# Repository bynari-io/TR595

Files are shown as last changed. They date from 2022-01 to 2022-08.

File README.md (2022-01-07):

# TR-595 Tricorder Project

This project is my attempt to build a customized version of the Voyager Mk IX/X Tricorder. The project will consist of a 3D printed housing and will utilize an LCD display and custom electronics driven by a Raspberry Pi Pico. All designs and code will be freely available in this repository. For more information, see the developmnent thread on the RPF: https://www.therpf.com/forums/threads/tr-595e-custom-tricorder.342650/

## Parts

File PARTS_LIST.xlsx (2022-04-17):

TR-595 Part List
2022 Arky's Lab
FRONT ARRAY
LABEL | TYPE | VALUE | PACKAGE | Notes
C1 | CAPACITOR | 4.7uF | 0805 SMD
C2 | CAPACITOR | 0.01uF | 0805 SMD
C3 | CAPACITOR | 2.2uF | 0805 SMD
C4 | CAPACITOR | 0.01uF | 0805 SMD
D1 | LED | AMBER | 0805 SMD | P/N 150080AS75000
D2 | LED | AMBER | 0805 SMD | P/N 150080AS75000
D3 | LED | AMBER | 0805 SMD | P/N 150080AS75000
D4 | LED | AMBER | 0805 SMD | P/N 150080AS75000
D5 | LED | AMBER | 0805 SMD | P/N 150080AS75000
D6 | LED | AMBER | 0805 SMD | P/N 150080AS75000
D7 | LED | AMBER | 0805 SMD | P/N 150080AS75000
D8 | LED | AMBER | 0805 SMD | P/N 150080AS75000
D9 | LED | GREEN | 0805 SMD | P/N 150080VS75000
D10 | LED | GREEN | 0805 SMD | P/N 150080VS75000
D11 | LED | GREEN | 0805 SMD | P/N 150080VS75000
D12 | LED | GREEN | 0805 SMD | P/N 150080VS75000
D13 | LED | GREEN | 0805 SMD | P/N 150080VS75000
D14 | LED | GREEN | 0805 SMD | P/N 150080VS75000
D15 | LED | GREEN | 0805 SMD | P/N 150080VS75000
D16 | LED | GREEN | 0805 SMD | P/N 150080VS75000
D17 | LED | GREEN | 0805 SMD | P/N 150080VS75000
D18 | LED | GREEN | 0805 SMD | P/N 150080VS75000
D19 | LED | GREEN | 0805 SMD | P/N 150080VS75000
D20 | LED | GREEN | 0805 SMD | P/N 150080VS75000
D21 | LED | GREEN | 0805 SMD | P/N 150080VS75000
D22 | LED | GREEN | 0805 SMD | P/N 150080VS75000
D23 | LED | AMBER | 0805 SMD | P/N 150080AS75000
D24 | LED | AMBER | 0805 SMD | P/N 150080AS75000
D25 | LED | AMBER | 0805 SMD | P/N 150080AS75000
D26 | LED | RED | 0805 SMD | P/N 150080SS75000
D27 | LED | RED | 0805 SMD | P/N 150080SS75000
D28 | LED | RED | 0805 SMD | P/N 150080SS75000
IC1 | IC | NE555_SOIC | SO16
IC2 | IC | NE555_SOIC | SO16
IC3 | IC | 4017D | SO16 | P/N 74HC4017D,653
IC4 | IC | 4017D | SO16 | P/N 74HC4017D,653
R1 | RESISTOR | 100K | 0805 SMD
R2 | RESISTOR | 200 | 0805 SMD
R3 | RESISTOR | 82 | 0805 SMD
R4 | RESISTOR | 100K | 0805 SMD
R5 | RESISTOR | 200 | 0805 SMD
R6 | RESISTOR | 82 | 0805 SMD
R7 | RESISTOR | 150 | 0805 SMD
R8 | RESISTOR | 150 | 0805 SMD
R9 | RESISTOR | 150 | 0805 SMD
R10 | RESISTOR | 150 | 0805 SMD
R11 | RESISTOR | 150 | 0805 SMD
R12 | RESISTOR | 150 | 0805 SMD
R13 | RESISTOR | 150 | 0805 SMD
R14 | RESISTOR | 150 | 0805 SMD
R15 | RESISTOR | 150 | 0805 SMD
R16 | RESISTOR | 150 | 0805 SMD
R17 | RESISTOR | 150 | 0805 SMD
R18 | RESISTOR | 150 | 0805 SMD
LOWER INTERFACE
LABEL | TYPE | VALUE | PACKAGE | Notes
C1 | CAPACITOR | 3.3uF | 0805 SMD
C2 | CAPACITOR | 0.01uF | 0805 SMD
D1 | LED | GREEN | 0805 SMD | P/N 150080VS75000
D2 | LED | GREEN | 0805 SMD | P/N 150080VS75000
D3 | LED | GREEN | 0805 SMD | P/N 150080VS75000
D4 | LED | GREEN | 0805 SMD | P/N 150080VS75000
D5 | LED | AMBER | 0805 SMD | P/N 150080AS75000
D6 | LED | AMBER | 0805 SMD | P/N 150080AS75000
D7 | LED | AMBER | 0805 SMD | P/N 150080AS75000
D8 | LED | AMBER | 0805 SMD | P/N 150080AS75000
D9 | LED | RED | 0805 SMD | P/N 150080SS75000
IC1 | IC | NE555_SOIC | SO16
IC2 | IC | 4017D | SO16 | P/N 74HC4017D,653
R1 | RESISTOR | 100K | 0805 SMD
R2 | RESISTOR | 200 | 0805 SMD
R3 | RESISTOR | 150 | 0805 SMD
R4 | RESISTOR | 150 | 0805 SMD
R5 | RESISTOR | 150 | 0805 SMD
R6 | RESISTOR | 150 | 0805 SMD
R7 | RESISTOR | 150 | 0805 SMD
R8 | RESISTOR | 150 | 0805 SMD
LOWER INTERFACE
LABEL | TYPE | VALUE | PACKAGE | Notes
D1 | LED | RED | 0805 SMD | P/N 150080SS75000
D2 | LED | GREEN | 0805 SMD | P/N 150080VS75000
D3 | LED | GREEN | 0805 SMD | P/N 150080VS75000
D4 | LED | RED | 0805 SMD | P/N 150080SS75000
D5 | LED | RED | 0805 SMD | P/N 150080SS75000
D6 | LED | AMBER | 0805 SMD | P/N 150080AS75000
D7 | LED | AMBER | 0805 SMD | P/N 150080AS75000
R1 | RESISTOR | 150 | 0805 SMD
R2 | RESISTOR | 150 | 0805 SMD
R3 | RESISTOR | 150 | 0805 SMD
R4 | RESISTOR | 150 | 0805 SMD
R5 | RESISTOR | 150 | 0805 SMD
R6 | RESISTOR | 150 | 0805 SMD
R7 | RESISTOR | 150 | 0805 SMD
OTHER
REED SWITCH |  | LITTELFUSE MAGNETIC/REED SWITCH P/N MDRR-DT-15-F
LCD SCREEN |  | https://www.adafruit.com/product/1480
BATTERY |  | https://www.adafruit.com/product/258
CHARGER |  | https://www.adafruit.com/product/1905
QI RECEIVER |  | https://www.digikey.com/en/products/detail/adafruit-industries-llc/1901/5629432
PAINT |  | DUPLICOLOR BGM0347 MEDIUM GRAY METALLIC
HINGES |  | STANLEY CLASSIC BRASSWARE 80-3050 3/4" (19mm)
MICROCONTROLLER |  | RASPBERRY PI PICO

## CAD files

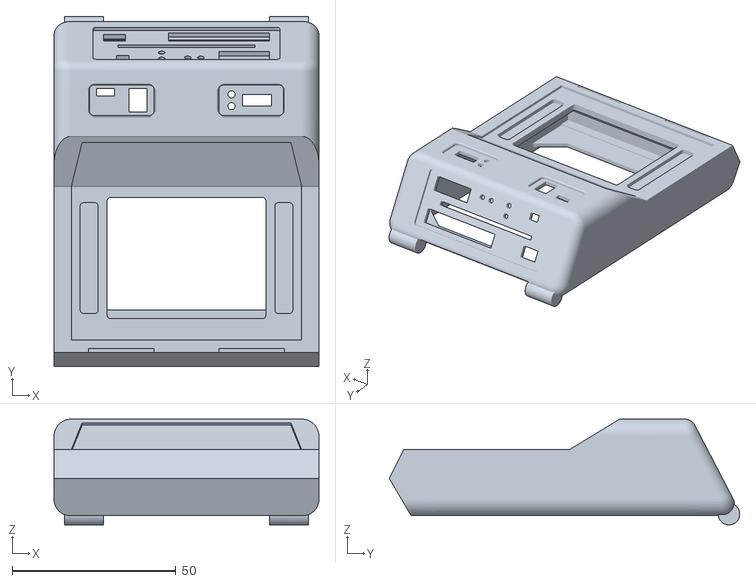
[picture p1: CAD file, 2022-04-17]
STL/Main Body.stl
81.0 x 107.1 x 32.3

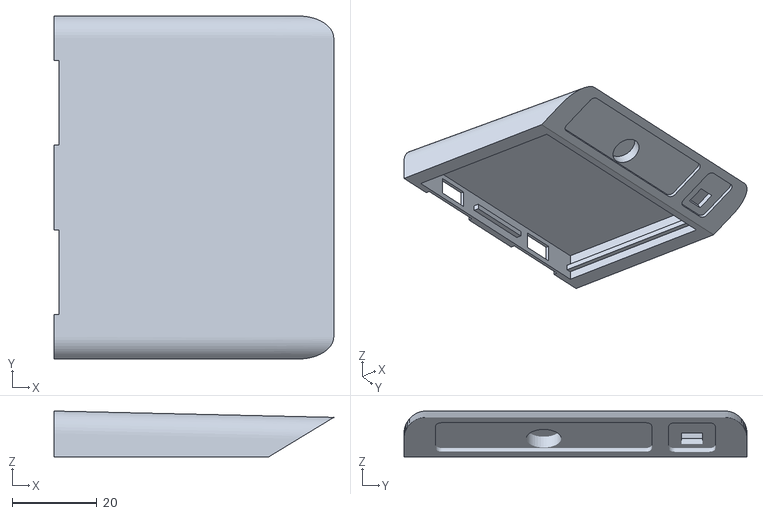
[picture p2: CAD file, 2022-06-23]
STL/Door 5.1 (ID Cutout).stl
66.0 x 81.0 x 10.9

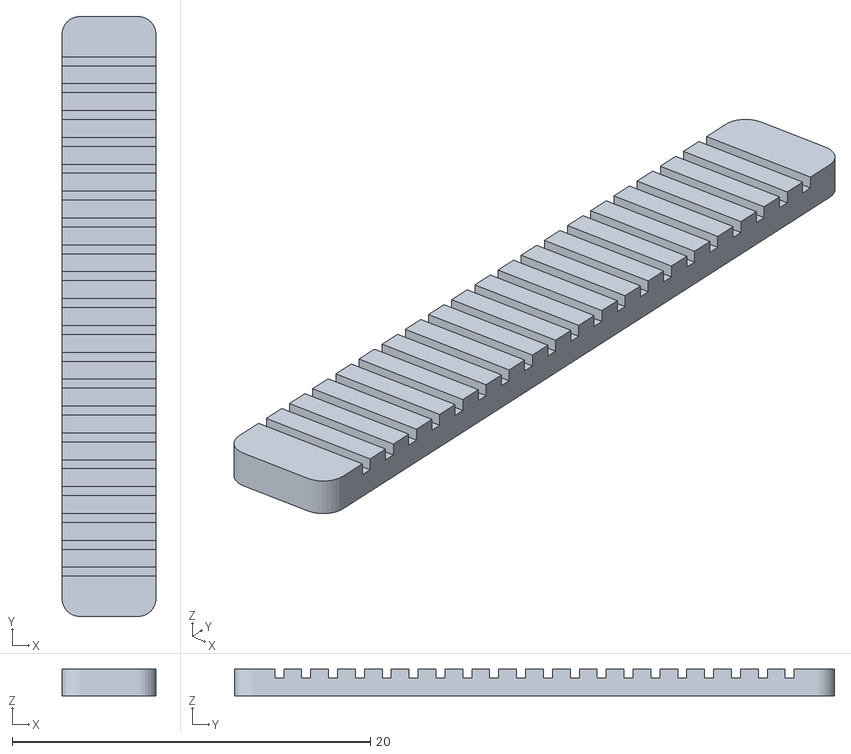
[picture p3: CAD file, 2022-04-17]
STL/Panel Greeblies.stl
5.25 x 33.5 x 1.50

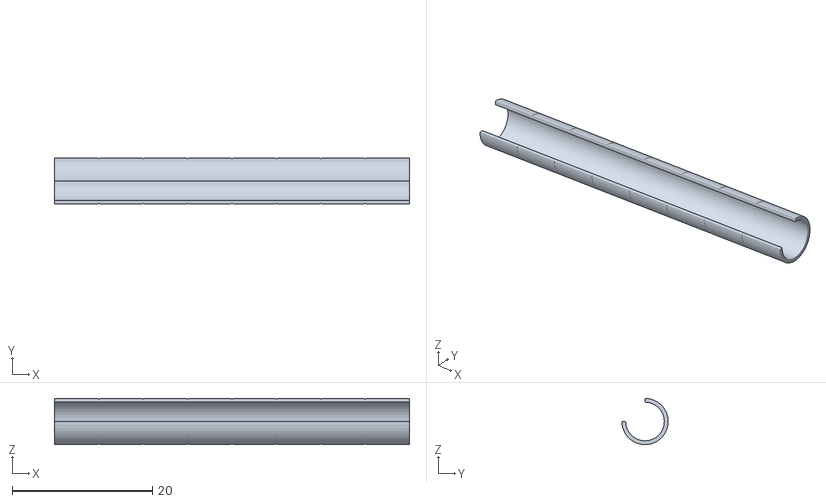
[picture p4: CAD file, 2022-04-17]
STL/Front Array Greeblie.stl
50.6 x 6.60 x 6.60

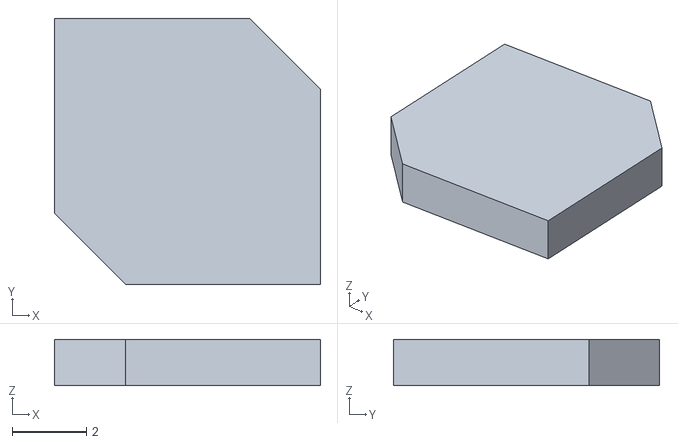
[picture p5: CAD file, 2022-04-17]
STL/EMRG.stl
7.16 x 7.15 x 1.25

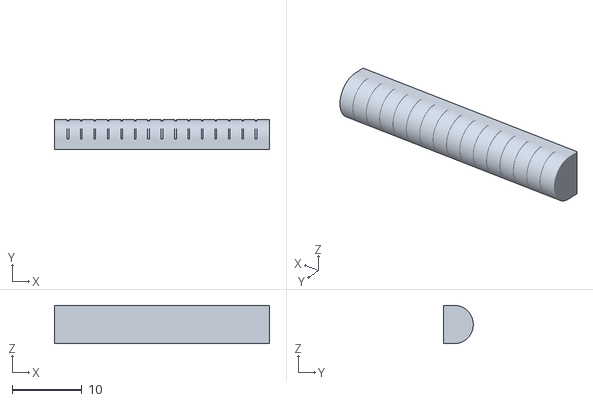
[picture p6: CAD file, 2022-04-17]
STL/Front Greeblie LG.stl
30.8 x 4.25 x 5.50

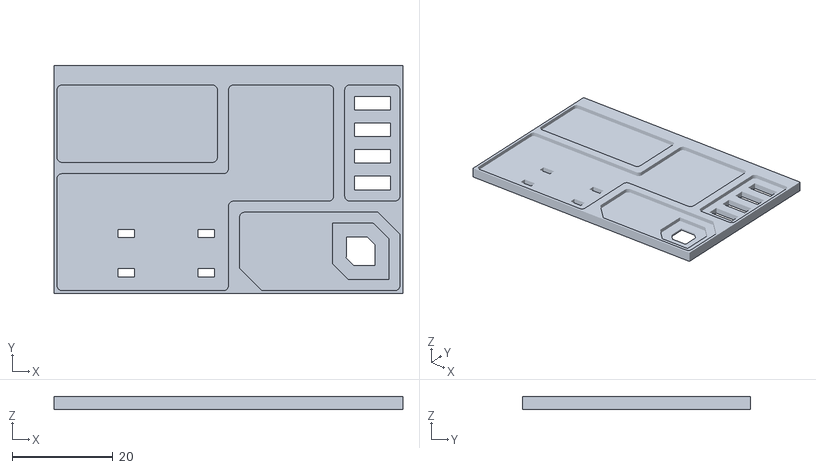
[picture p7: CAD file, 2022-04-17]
STL/Lower Interface.stl
69.4 x 45.4 x 2.50

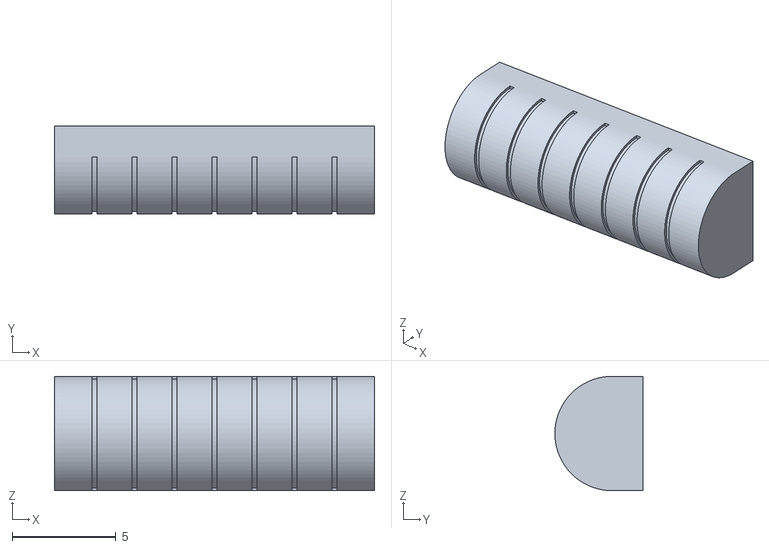
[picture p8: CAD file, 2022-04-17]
STL/Front Greeblie SM.stl
15.4 x 4.25 x 5.50

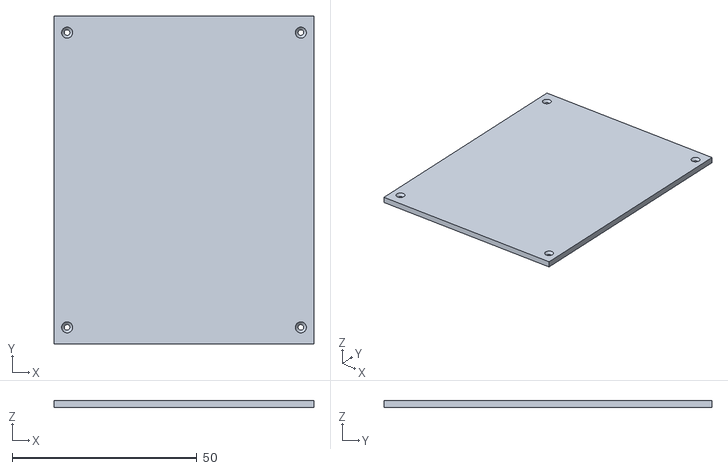
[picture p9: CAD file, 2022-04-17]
STL/Back Panel.stl
70.2 x 88.8 x 2.00

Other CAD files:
STL/Door.stl
F360 Exports/Back Panel.f3d
F360 Exports/Door 5.1 (ID Cutout).f3z
F360 Exports/Door.f3z
F360 Exports/EMRG.f3d
F360 Exports/Electronics/Lower Interface Electronics.f3z
F360 Exports/Electronics/Top Panel Electronics.f3z
F360 Exports/Front Array Greeblie.f3d
F360 Exports/Front Greeblie LG.f3d
F360 Exports/Front Greeblie SM.f3d
F360 Exports/Lower Interface.f3d
F360 Exports/Main Body.f3z
F360 Exports/Panel Greeblie.f3d

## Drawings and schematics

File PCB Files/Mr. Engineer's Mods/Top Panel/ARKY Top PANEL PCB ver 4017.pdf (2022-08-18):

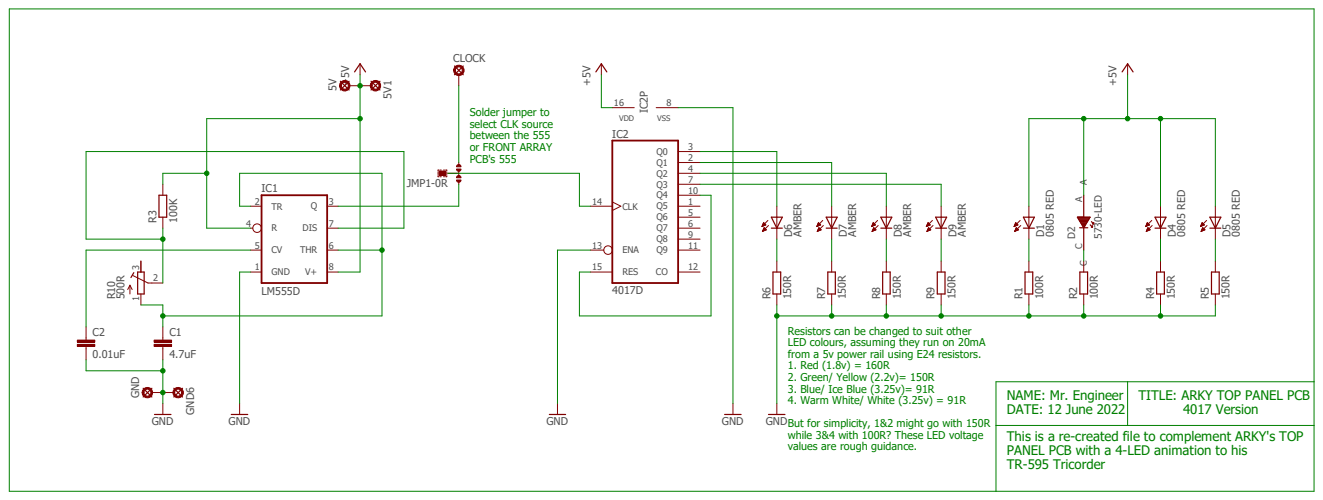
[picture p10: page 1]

Resistors can be changed to suit other
LED colours, assuming they run on 20mA
from a 5v power rail using E24 resistors.
1. Red (1.8v) = 160R
2. Green/ Yellow (2.2v)= 150R
3. Blue/ Ice Blue (3.25v)= 91R
4. Warm White/ White (3.25v) = 91R
But for simplicity, 1&2 might go with 150R
while 3&4 with 100R? These LED voltage
values are rough guidance.

NAME: Mr. Engineer
DATE: 12 June 2022
This is a re-created file to complement ARKY's TOP
PANEL PCB with a 4-LED animation to his
TR-595 Tricorder

TITLE: ARKY TOP PANEL PCB
4017 Version

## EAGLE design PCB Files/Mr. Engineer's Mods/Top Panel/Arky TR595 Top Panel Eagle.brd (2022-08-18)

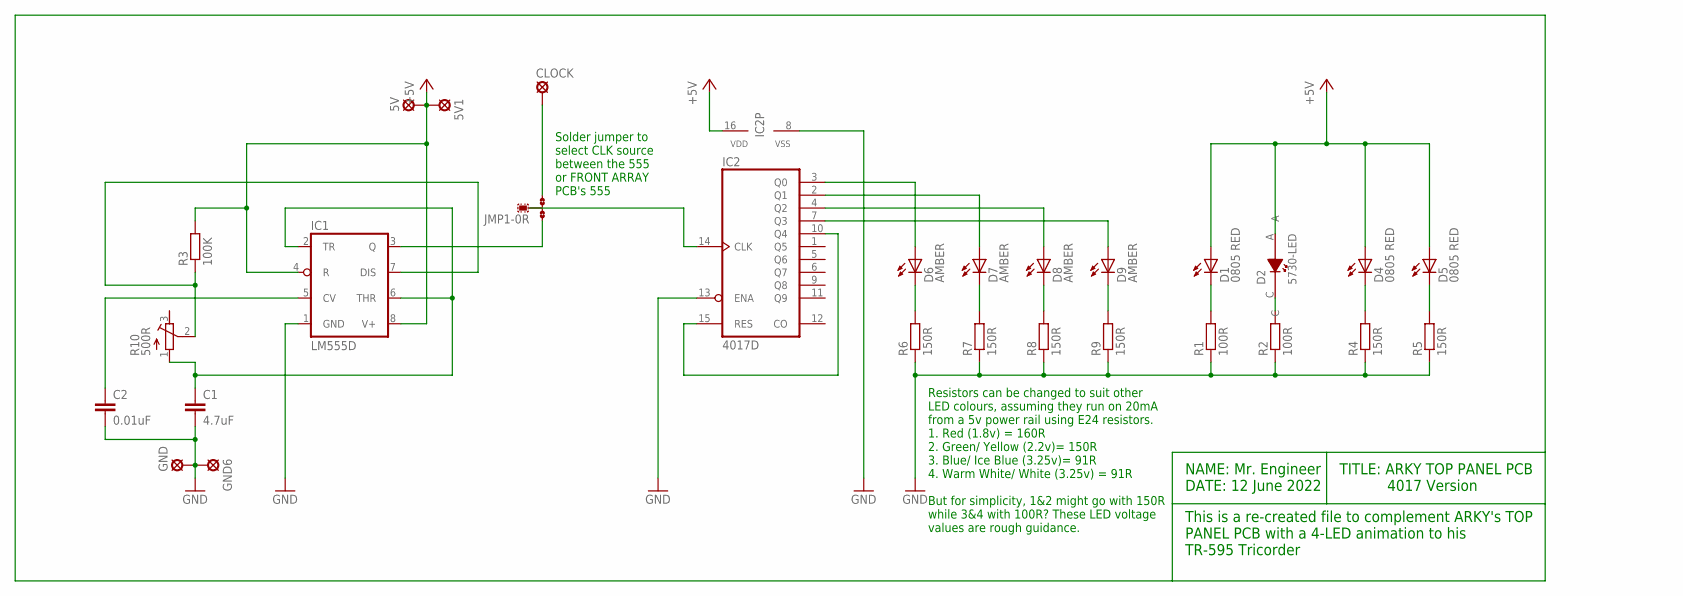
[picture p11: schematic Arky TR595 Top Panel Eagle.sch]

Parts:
5V, 5V1: MCS10B
C1: 4.7uF; C0805
C2: 0.01uF; C0805
CLOCK: MCS10B
D1, D4, D5: 0805 RED; CHIPLED_0805
D2: 5730-LED
D6, D7, D8, D9: AMBER; CHIPLED_0805
GND, GND6: MCS10B
IC1: LM555D; SO08
IC2: 4017D; SO16
JMP1: 0R-JUMPA; A0R-JMP
R1, R2: 100R; R0805
R3: 100K; R0805
R4, R5, R6, R7, R8, R9: 150R; R0805
R10: 500R; RTRIM3103

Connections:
+5V: 5V.MP, 5V1.MP, D1.A, D2.A, D4.A, D5.A, IC1.4 (R), IC1.8 (V+), IC2.16 (VDD), R3.2
GND: IC2.8 (VSS)
unnamed: IC1.3 (Q), JMP1.1
unnamed: C2.1, IC1.5 (CV)
unnamed: D6.C, R6.2
unnamed: D7.C, R7.2
unnamed: D8.C, R8.2
unnamed: D9.C, R9.2
unnamed: C1.1, IC1.2 (TR), IC1.6 (THR), R10.1 (A)
unnamed: D6.A, IC2.3 (Q0)
unnamed: D7.A, IC2.2 (Q1)
unnamed: D8.A, IC2.4 (Q2)
unnamed: D9.A, IC2.7 (Q3)
unnamed: IC2.10 (Q4), IC2.15 (RES)
unnamed: D4.C, R4.2
unnamed: D5.C, R5.2
unnamed: D1.C, R1.2
unnamed: D2.C, R2.2
unnamed: IC1.7 (DIS), R3.1, R10.2 (S)
unnamed: IC2.14 (CLK), JMP1.2
unnamed: CLOCK.MP, JMP1.3
unnamed: C1.2, C2.2, GND.MP, GND6.MP, IC1.1 (GND), IC2.13 (ENA), R1.1, R2.1, R4.1, R5.1, R6.1, R7.1, R8.1, R9.1

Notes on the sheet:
This is a re-created file to complement ARKY's TOP PANEL PCB with a 4-LED animation to his TR-595 Tricorder
NAME: Mr. Engineer DATE: 12 June 2022
TITLE: ARKY TOP PANEL PCB 4017 Version
Solder jumper to select CLK source between the 555 or FRONT ARRAY PCB's 555
Resistors can be changed to suit other LED colours, assuming they run on 20mA from a 5v power rail using E24 resistors. 1. Red (1.8v) = 160R 2. Green/ Yellow (2.2v)= 150R 3. Blue/ Ice Blue (3.25v)= 91R 4. Warm White/ White (3.25v) = 91R But for simplicity, 1&2 might go with 150R while 3&4 with 100R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

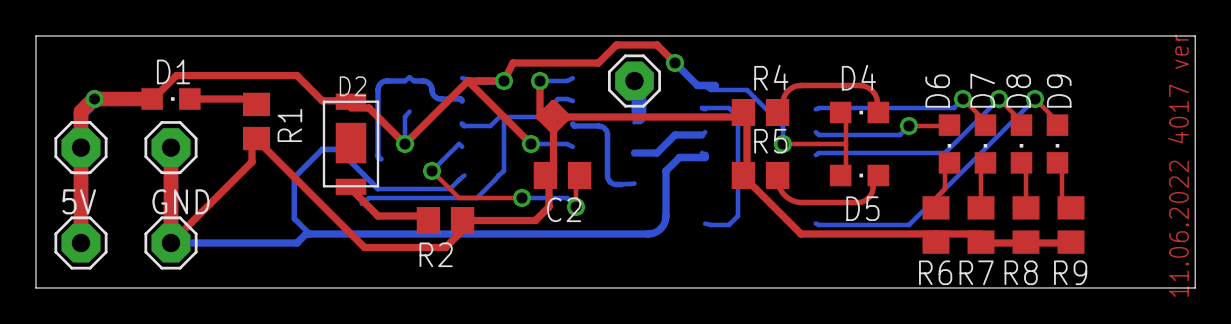
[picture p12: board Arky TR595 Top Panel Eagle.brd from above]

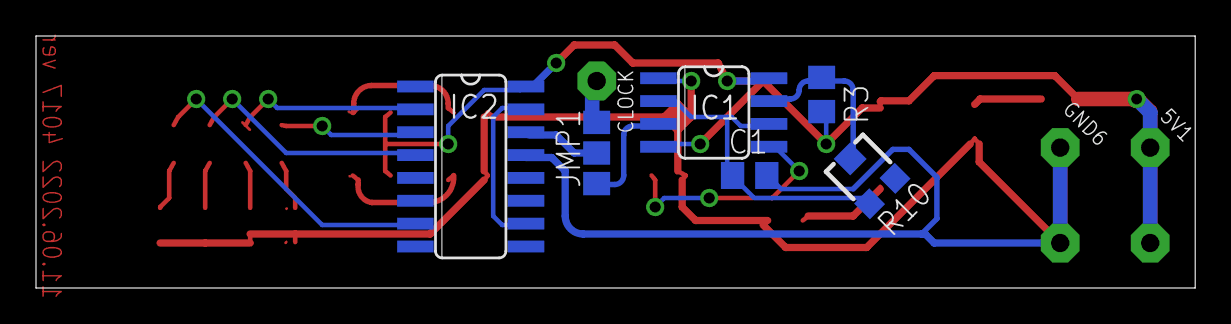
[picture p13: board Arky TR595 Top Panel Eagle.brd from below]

Board: 2 copper layers, 64.4 x 14.0 mm, 28 parts (6 on the bottom side), 21 nets.

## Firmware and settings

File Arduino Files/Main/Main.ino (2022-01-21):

// Libraries
#include <TFT_eSPI.h>
#include "tr595.h"

// Assets
#include "defaultmode.h"
#include "dm_button_red.h"
#include "dm_button_orange.h"
#include "dm_line1_orange.h"
#include "dm_line2_orange.h"
#include "dm_line3_orange.h"
#include "dm_line4_orange.h"
#include "dm_line5_orange.h"
#include "dm_line6_orange.h"
#include "dm_line1_white.h"
#include "dm_line2_white.h"
#include "dm_line3_white.h"
#include "dm_line4_white.h"
#include "dm_line5_white.h"
#include "dm_line6_white.h"


//TFT_eSPI instance
TFT_eSPI tft = TFT_eSPI();

// Constants
const int DISPLAY_WIDTH = 320;
const int DISPLAY_HEIGHT = 240;

// Sprites

// **Default Mode** //
TFT_eSprite dm_spr_frameTop = TFT_eSprite(&tft);
TFT_eSprite dm_bg_frameTop = TFT_eSprite(&tft);
TFT_eSprite dm_spr_frameBottom = TFT_eSprite(&tft);
TFT_eSprite dm_bg_frameBottom = TFT_eSprite(&tft);
TFT_eSprite dm_bg_button = TFT_eSprite(&tft);
TFT_eSprite dm_spr_barGraph = TFT_eSprite(&tft);
TFT_eSprite dm_bg_barGraph = TFT_eSprite(&tft);
TFT_eSprite dm_bg_scrollText = TFT_eSprite(&tft);

// Animation Elements

// **Default Mode** //
Anim dm_frameTop;
Anim dm_frameBottom;
Anim dm_button1;
Anim dm_button2;
Anim dm_button3;
Anim dm_bargraph1;
Anim dm_bargraph2;
Anim dm_bargraph3;
Anim dm_bargraph4;
Anim dm_bargraph5;
Anim dm_bargraph6;
Anim dm_bargraph7;
Anim dm_bargraph8;
Anim dm_line1;
Anim dm_line2;
Anim dm_line3;
Anim dm_line4;
Anim dm_line5;
Anim dm_line6;


// Variables
unsigned long currentMillis = 0;

// Functions

void setup() {

  pinMode(LED_BUILTIN, OUTPUT); // Used for diagnostic purposes
  
  // Initialize TFT & clear the screen
  TFTSetup();
  tft.fillScreen(TFT_BLACK);

  //Initialize all modes
  DM_InitializeAttributes();
  randomSeed(millis());

  // Begin Default Mode animation sequence
  DM_Loop(); 
}

void loop() {  
}

void TFTSetup(){

  Serial.begin(115200);
  tft.begin();
  tft.setRotation(1); // Set display to landscape

  //Swap the color byte order when rendering
  tft.setSwapBytes(true);
    
}

void DrawBackgroundImage(int x, int y, int w, int h, const unsigned short IMAGE[]) {

  // Clear screen & draw background image
  //tft.fillScreen(TFT_BLACK);
  tft.pushImage(x, y, w, h, IMAGE);
      
}

void ShowLED() {
  digitalWrite(LED_BUILTIN, HIGH);   // turn the LED on (HIGH is the voltage level)                   
}

/////////////////////
// ANIMATION LOGIC //
/////////////////////

// ***** DEFAULT MODE *** ////////////////////////////////////////////////////////////////

void DM_InitializeAttributes(){

// Text Line 1
dm_line1.sizeX = 171;    // Size attributes will be used for the entire sequence
dm_line1.sizeY = 4;
dm_line1.currentX = 70;
dm_line1.currentY = 8;
dm_line1.interval = 500; // This interval will be used for the entire sequence
dm_line1.sCounter = 0;   // This counter will be used for the entire sequence
dm_line1.previousMillis = 0;   // This will be used for the entire sequence


// Text Line 2
dm_line2.currentX = 70;
dm_line2.currentY = 13;

// Text Line 3
dm_line3.currentX = 70;
dm_line3.currentY = 18;

//Text Line 4
dm_line4.currentX = 70;
dm_line4.currentY = 23;

// Text Line 5
dm_line5.currentX = 70;
dm_line5.currentY = 28;

//Text Line 6
dm_line6.currentX = 70;
dm_line6.currentY = 33;

// Bargraph 1
dm_bargraph1.sizeX = 23;
dm_bargraph1.sizeY = 5;
dm_bargraph1.maxX = 23;
dm_bargraph1.maxY = 95;
dm_bargraph1.currentX = 92;
dm_bargraph1.currentY = dm_bargraph1.bargraphBottom - dm_bargraph1.sizeY;
dm_bargraph1.bargraphBottom = 188;
dm_bargraph1.interval = 20;
dm_bargraph1.bargraphSpeed = 1;

// Bargraph 2
dm_bargraph2.sizeX = 23;
dm_bargraph2.sizeY = 5;
dm_bargraph2.maxX = 23;
dm_bargraph2.maxY = 95;
dm_bargraph2.currentX = 117;
dm_bargraph2.currentY = dm_bargraph2.bargraphBottom - dm_bargraph2.sizeY;
dm_bargraph2.bargraphBottom = 188;
dm_bargraph2.interval = 20;
dm_bargraph2.bargraphSpeed = 1;

// Bargraph 3
dm_bargraph3.sizeX = 23;
dm_bargraph3.sizeY = 5;
dm_bargraph3.maxX = 23;
dm_bargraph3.maxY = 95;
dm_bargraph3.currentX = 142;
dm_bargraph3.currentY = dm_bargraph1.bargraphBottom - dm_bargraph1.sizeY;
dm_bargraph3.bargraphBottom = 188;
dm_bargraph3.interval = 20;
dm_bargraph3.bargraphSpeed = 1;

// Bargraph 4
dm_bargraph4.sizeX = 23;
dm_bargraph4.sizeY = 5;
dm_bargraph4.maxX = 23;
dm_bargraph4.maxY = 95;
dm_bargraph4.currentX = 167;
dm_bargraph4.currentY = dm_bargraph4.bargraphBottom - dm_bargraph4.sizeY;
dm_bargraph4.bargraphBottom = 188;
dm_bargraph4.interval = 20;
dm_bargraph4.bargraphSpeed = 1;

// Bargraph 5
dm_bargraph5.sizeX = 23;
dm_bargraph5.sizeY = 5;
dm_bargraph5.maxX = 23;
dm_bargraph5.maxY = 95;
dm_bargraph5.currentX = 192;
dm_bargraph5.currentY = dm_bargraph5.bargraphBottom - dm_bargraph5.sizeY;
dm_bargraph5.bargraphBottom = 188;
dm_bargraph5.interval = 20;
dm_bargraph5.bargraphSpeed = 1;

// Bargraph 6
dm_bargraph6.sizeX = 23;
dm_bargraph6.sizeY = 5;
dm_bargraph6.maxX = 23;
dm_bargraph6.maxY = 95;
dm_bargraph6.currentX = 217;
dm_bargraph6.currentY = dm_bargraph6.bargraphBottom - dm_bargraph6.sizeY;
dm_bargraph6.bargraphBottom = 188;
dm_bargraph6.interval = 20;
dm_bargraph6.bargraphSpeed = 1;

// Bargraph 7
dm_bargraph7.sizeX = 23;
dm_bargraph7.sizeY = 5;
dm_bargraph7.maxX = 23;
dm_bargraph7.maxY = 95;
dm_bargraph7.currentX = 242;
dm_bargraph7.currentY = dm_bargraph7.bargraphBottom - dm_bargraph7.sizeY;
dm_bargraph7.bargraphBottom = 188;
dm_bargraph7.interval = 20;
dm_bargraph7.bargraphSpeed = 1;

// Bargraph 8
dm_bargraph8.sizeX = 23;
dm_bargraph8.sizeY = 5;
dm_bargraph8.maxX = 23;
dm_bargraph8.maxY = 95;
dm_bargraph8.currentX = 267;
dm_bargraph8.currentY = dm_bargraph8.bargraphBottom - dm_bargraph8.sizeY;
dm_bargraph8.bargraphBottom = 188;
dm_bargraph8.interval = 20;
dm_bargraph8.bargraphSpeed = 1;

// Button 1
dm_button1.sizeX = 32;
dm_button1.sizeY = 12;
dm_button1.currentX = 211;
dm_button1.currentY = 214;
dm_button1.interval = 2000;

// Button 2
dm_button2.sizeX = 32;
dm_button2.sizeY = 12;
dm_button2.currentX = 245;
dm_button2.currentY = 214;
dm_button2.interval = 500;

// Button 3
dm_button3.sizeX = 32;
dm_button3.sizeY = 12;
dm_button3.currentX = 279;
dm_button3.currentY = 214;
dm_button3.interval = 750;

// Frame Top
dm_frameTop.sizeX = 8;
dm_frameTop.sizeY = 5;
dm_frameTop.minX = 136;
dm_frameTop.minY = 59;
dm_frameTop.maxX = 173;
dm_frameTop.maxY = 59;
dm_frameTop.currentX = dm_frameTop.maxX;
dm_frameTop.currentY = dm_frameTop.minY;
dm_frameTop.oldX = dm_frameTop.currentX;
dm_frameTop.oldY = dm_frameTop.currentY;
dm_frameTop.reverse = true;
dm_frameTop.interval = 20;

// Frame Bottom
dm_frameBottom.sizeX = 8;
dm_frameBottom.sizeY = 5;
dm_frameBottom.minX = 136;
dm_frameBottom.minY = 230;
dm_frameBottom.maxX = 173;
dm_frameBottom.maxY = 230;
dm_frameBottom.currentX = dm_frameBottom.minX;
dm_frameBottom.currentY = dm_frameBottom.minY;
dm_frameBottom.oldX = dm_frameBottom.currentX;
dm_frameBottom.oldY = dm_frameBottom.currentY;
dm_frameBottom.reverse = false;
dm_frameBottom.interval = 20;

}

// Begin Default Mode Loop
void DM_Loop(){

  DrawBackgroundImage(0, 0, DISPLAY_WIDTH, DISPLAY_HEIGHT, defaultmode);

  while(true){

    currentMillis = millis();
    DM_FrameTop();
    DM_FrameBottom();
    DM_Button1();
    DM_Button2();
    DM_Button3();
    DM_Bargraph1();
    DM_Bargraph2();
    DM_Bargraph3();
    DM_Bargraph4();
    DM_Bargraph5();
    DM_Bargraph6();
    DM_Bargraph7();
    DM_Bargraph8();
    DM_ScrollingText();
    
  }
   
}

void DM_ScrollingText(){

  if (CheckTime(currentMillis, dm_line1.previousMillis, dm_line1.interval)) {

    if (dm_line1.sCounter == 0){
      // Draw first line
      DrawBackgroundImage(dm_line1.currentX, dm_line1.currentY, dm_line1.sizeX, dm_line1.sizeY, dm_line1_orange);

    }

    if (dm_line1.sCounter == 1){
      // Draw second line
      DrawBackgroundImage(dm_line2.currentX, dm_line2.currentY, dm_line1.sizeX, dm_line1.sizeY, dm_line2_orange);

    }

    if (dm_line1.sCounter == 2){
      // Draw third line
      DrawBackgroundImage(dm_line3.currentX, dm_line3.currentY, dm_line1.sizeX, dm_line1.sizeY, dm_line3_orange);

    }

    if (dm_line1.sCounter == 3){
      // Draw fourth line
      DrawBackgroundImage(dm_line4.currentX, dm_line4.currentY, dm_line1.sizeX, dm_line1.sizeY, dm_line4_orange);

    }
    
    if (dm_line1.sCounter == 4){
      // Draw fifth line
      DrawBackgroundImage(dm_line5.currentX, dm_line5.currentY, dm_line1.sizeX, dm_line1.sizeY, dm_line5_orange);

    }
    
    if (dm_line1.sCounter == 5){
      // Draw sixth line
      DrawBackgroundImage(dm_line6.currentX, dm_line6.currentY, dm_line1.sizeX, dm_line1.sizeY, dm_line6_orange);

    }

    if (dm_line1.sCounter == 6){
      // highlight first and second lines
      DrawBackgroundImage(dm_line1.currentX, dm_line1.currentY, dm_line1.sizeX, dm_line1.sizeY, dm_line1_white);
      DrawBackgroundImage(dm_line2.currentX, dm_line2.currentY, dm_line1.sizeX, dm_line1.sizeY, dm_line2_white);

    }

    if (dm_line1.sCounter == 7){
      // restore first and second lines, highlight third and fourth lines
      DrawBackgroundImage(dm_line1.currentX, dm_line1.currentY, dm_line1.sizeX, dm_line1.sizeY, dm_line1_orange);
      DrawBackgroundImage(dm_line2.currentX, dm_line2.currentY, dm_line1.sizeX, dm_line1.sizeY, dm_line2_orange);
      
      DrawBackgroundImage(dm_line3.currentX, dm_line3.currentY, dm_line1.sizeX, dm_line1.sizeY, dm_line3_white);
      DrawBackgroundImage(dm_line4.currentX, dm_line4.currentY, dm_line1.sizeX, dm_line1.sizeY, dm_line4_white);

    }

    if (dm_line1.sCounter == 8){
      // restore third and fourth lines, highlight fifth and sixth lines
      DrawBackgroundImage(dm_line3.currentX, dm_line3.currentY, dm_line1.sizeX, dm_line1.sizeY, dm_line3_orange);
      DrawBackgroundImage(dm_line4.currentX, dm_line4.currentY, dm_line1.sizeX, dm_line1.sizeY, dm_line4_orange);
      
      DrawBackgroundImage(dm_line5.currentX, dm_line5.currentY, dm_line1.sizeX, dm_line1.sizeY, dm_line5_white);
      DrawBackgroundImage(dm_line6.currentX, dm_line6.currentY, dm_line1.sizeX, dm_line1.sizeY, dm_line6_white);

    }

    if (dm_line1.sCounter == 9){
      // restore fifth and sixth lines
      DrawBackgroundImage(dm_line5.currentX, dm_line5.currentY, dm_line1.sizeX, dm_line1.sizeY, dm_line5_orange);
      DrawBackgroundImage(dm_line6.currentX, dm_line6.currentY, dm_line1.sizeX, dm_line1.sizeY, dm_line6_orange);

    }

    if (dm_line1.sCounter == 10){
      // Erase all text
      dm_bg_scrollText.createSprite(174, 31);
      dm_bg_scrollText.fillSprite(TFT_BLACK);
      dm_bg_scrollText.pushSprite(68, 7);
      dm_bg_scrollText.deleteSprite();

      // Reset counter to end sequence
      dm_line1.sCounter = 0;
      dm_line1.previousMillis = currentMillis;
      return;
    }
    
    dm_line1.sCounter++;
    dm_line1.previousMillis = currentMillis;
  }
  
}

void DM_Bargraph1(){

  if (CheckTime(currentMillis, dm_bargraph1.previousMillis, dm_bargraph1.interval)){
    if (dm_bargraph1.sCounter == 0) {
      // Generate the next value for the bargraph, then flag the sequence counter
      dm_bargraph1.newY = random(dm_bargraph1.minY, (dm_bargraph1.maxY));

      dm_bargraph1.sCounter = 1;   
    }

    if (dm_bargraph1.newY >= dm_bargraph1.sizeY) {
      // Increase the bargraph size
      dm_bargraph1.sizeY = dm_bargraph1.sizeY + dm_bargraph1.bargraphSpeed;
      
      // Calculate the new position of the bar
      dm_bargraph1.currentY = dm_bargraph1.bargraphBottom - dm_bargraph1.sizeY;

      // Draw the new bargraph
      dm_spr_barGraph.createSprite(dm_bargraph1.sizeX, dm_bargraph1.sizeY);
      dm_spr_barGraph.fillSprite(TFT_RED);
      dm_spr_barGraph.pushSprite(dm_bargraph1.currentX, dm_bargraph1.currentY);
      dm_spr_barGraph.deleteSprite();

      if (dm_bargraph1.sizeY >= dm_bargraph1.newY){
      // Once the bargraph meets the new value, reset the sequence counter so a new value can be generated
      dm_bargraph1.sCounter = 0;
      }       
    }
    
    if (dm_bargraph1.newY < dm_bargraph1.sizeY){      
      // Decrease the bargraph size
      dm_bargraph1.sizeY = dm_bargraph1.sizeY - dm_bargraph1.bargraphSpeed;

      // To shrink the bar, we'll need to draw a black sprite over the top part of the bar.
            
      // Draw the black sprite
      dm_bg_barGraph.createSprite(dm_bargraph1.maxX, dm_bargraph1.maxY - dm_bargraph1.sizeY);
      dm_bg_barGraph.fillSprite(TFT_BLACK);
      dm_bg_barGraph.pushSprite(dm_bargraph1.currentX, dm_bargraph1.maxY - 2);
      dm_bg_barGraph.deleteSprite();
     
      
      if (dm_bargraph1.sizeY <= dm_bargraph1.newY){
      // Once the bargraph meets the new value, reset the sequence counter so a new value can be generated
      dm_bargraph1.sCounter = 0;
        }
    }    

    dm_bargraph1.previousMillis = currentMillis;    
  }
  
}

void DM_Bargraph2(){

  if (CheckTime(currentMillis, dm_bargraph2.previousMillis, dm_bargraph2.interval)){
    if (dm_bargraph2.sCounter == 0) {
      // Generate the next value for the bargraph, then flag the sequence counter
      dm_bargraph2.newY = random(dm_bargraph2.minY, (dm_bargraph2.maxY));

      dm_bargraph2.sCounter = 1;   
    }

    if (dm_bargraph2.newY >= dm_bargraph2.sizeY) {
      // Increase the bargraph size
      dm_bargraph2.sizeY = dm_bargraph2.sizeY + dm_bargraph2.bargraphSpeed;
      
      // Calculate the new position of the bar
      dm_bargraph2.currentY = dm_bargraph2.bargraphBottom - dm_bargraph2.sizeY;

      // Draw the new bargraph
      dm_spr_barGraph.createSprite(dm_bargraph2.sizeX, dm_bargraph2.sizeY);
      dm_spr_barGraph.fillSprite(TFT_RED);
      dm_spr_barGraph.pushSprite(dm_bargraph2.currentX, dm_bargraph2.currentY);
      dm_spr_barGraph.deleteSprite();

      if (dm_bargraph2.sizeY >= dm_bargraph2.newY){
      // Once the bargraph meets the new value, reset the sequence counter so a new value can be generated
      dm_bargraph2.sCounter = 0;
      }       
    }
    
    if (dm_bargraph2.newY < dm_bargraph2.sizeY){      
      // Decrease the bargraph size
      dm_bargraph2.sizeY = dm_bargraph2.sizeY - dm_bargraph2.bargraphSpeed;

      // To shrink the bar, we'll need to draw a black sprite over the top part of the bar.
            
      // Draw the black sprite
      dm_bg_barGraph.createSprite(dm_bargraph2.maxX, dm_bargraph2.maxY - dm_bargraph2.sizeY);
      dm_bg_barGraph.fillSprite(TFT_BLACK);
      dm_bg_barGraph.pushSprite(dm_bargraph2.currentX, dm_bargraph2.maxY - 2);
      dm_bg_barGraph.deleteSprite();
     
      
      if (dm_bargraph2.sizeY <= dm_bargraph2.newY){
      // Once the bargraph meets the new value, reset the sequence counter so a new value can be generated
      dm_bargraph2.sCounter = 0;
        }
    }    

    dm_bargraph2.previousMillis = currentMillis;    
  }
  
}

void DM_Bargraph3(){

  if (CheckTime(currentMillis, dm_bargraph3.previousMillis, dm_bargraph3.interval)){
    if (dm_bargraph3.sCounter == 0) {
      // Generate the next value for the bargraph, then flag the sequence counter
      dm_bargraph3.newY = random(dm_bargraph3.minY, (dm_bargraph3.maxY));

      dm_bargraph3.sCounter = 1;   
    }

    if (dm_bargraph3.newY >= dm_bargraph3.sizeY) {
      // Increase the bargraph size
      dm_bargraph3.sizeY = dm_bargraph3.sizeY + dm_bargraph3.bargraphSpeed;
      
      // Calculate the new position of the bar
      dm_bargraph3.currentY = dm_bargraph3.bargraphBottom - dm_bargraph3.sizeY;

      // Draw the new bargraph
      dm_spr_barGraph.createSprite(dm_bargraph3.sizeX, dm_bargraph3.sizeY);
      dm_spr_barGraph.fillSprite(TFT_RED);
      dm_spr_barGraph.pushSprite(dm_bargraph3.currentX, dm_bargraph3.currentY);
      dm_spr_barGraph.deleteSprite();

      if (dm_bargraph3.sizeY >= dm_bargraph3.newY){
      // Once the bargraph meets the new value, reset the sequence counter so a new value can be generated
      dm_bargraph3.sCounter = 0;
      }       
    }
    
    if (dm_bargraph3.newY < dm_bargraph3.sizeY){      
      // Decrease the bargraph size
      dm_bargraph3.sizeY = dm_bargraph3.sizeY - dm_bargraph3.bargraphSpeed;

      // To shrink the bar, we'll need to draw a black sprite over the top part of the bar.
            
      // Draw the black sprite
      dm_bg_barGraph.createSprite(dm_bargraph3.maxX, dm_bargraph3.maxY - dm_bargraph3.sizeY);
      dm_bg_barGraph.fillSprite(TFT_BLACK);
      dm_bg_barGraph.pushSprite(dm_bargraph3.currentX, dm_bargraph3.maxY - 2);
      dm_bg_barGraph.deleteSprite();
     
      
      if (dm_bargraph3.sizeY <= dm_bargraph3.newY){
      // Once the bargraph meets the new value, reset the sequence counter so a new value can be generated
      dm_bargraph3.sCounter = 0;
        }
    }    

    dm_bargraph3.previousMillis = currentMillis;    
  }
  
}

void DM_Bargraph4(){

  if (CheckTime(currentMillis, dm_bargraph4.previousMillis, dm_bargraph4.interval)){
    if (dm_bargraph4.sCounter == 0) {
      // Generate the next value for the bargraph, then flag the sequence counter
      dm_bargraph4.newY = random(dm_bargraph4.minY, (dm_bargraph4.maxY));

      dm_bargraph4.sCounter = 1;   
    }

    if (dm_bargraph4.newY >= dm_bargraph4.sizeY) {
      // Increase the bargraph size
      dm_bargraph4.sizeY = dm_bargraph4.sizeY + dm_bargraph4.bargraphSpeed;
      
      // Calculate the new position of the bar
      dm_bargraph4.currentY = dm_bargraph4.bargraphBottom - dm_bargraph4.sizeY;

      // Draw the new bargraph
      dm_spr_barGraph.createSprite(dm_bargraph4.sizeX, dm_bargraph4.sizeY);
      dm_spr_barGraph.fillSprite(TFT_RED);
      dm_spr_barGraph.pushSprite(dm_bargraph4.currentX, dm_bargraph4.currentY);
      dm_spr_barGraph.deleteSprite();

      if (dm_bargraph4.sizeY >= dm_bargraph4.newY){
      // Once the bargraph meets the new value, reset the sequence counter so a new value can be generated
      dm_bargraph4.sCounter = 0;
      }       
    }
    
    if (dm_bargraph4.newY < dm_bargraph4.sizeY){      
      // Decrease the bargraph size
      dm_bargraph4.sizeY = dm_bargraph4.sizeY - dm_bargraph4.bargraphSpeed;

      // To shrink the bar, we'll need to draw a black sprite over the top part of the bar.
            
      // Draw the black sprite
      dm_bg_barGraph.createSprite(dm_bargraph4.maxX, dm_bargraph4.maxY - dm_bargraph4.sizeY);
      dm_bg_barGraph.fillSprite(TFT_BLACK);
      dm_bg_barGraph.pushSprite(dm_bargraph4.currentX, dm_bargraph4.maxY - 2);
      dm_bg_barGraph.deleteSprite();
     
      
      if (dm_bargraph4.sizeY <= dm_bargraph4.newY){
      // Once the bargraph meets the new value, reset the sequence counter so a new value can be generated
      dm_bargraph4.sCounter = 0;
        }
    }    

    dm_bargraph4.previousMillis = currentMillis;    
  }
  
}

void DM_Bargraph5(){

  if (CheckTime(currentMillis, dm_bargraph5.previousMillis, dm_bargraph5.interval)){
    if (dm_bargraph5.sCounter == 0) {
      // Generate the next value for the bargraph, then flag the sequence counter
      dm_bargraph5.newY = random(dm_bargraph5.minY, (dm_bargraph5.maxY));

      dm_bargraph5.sCounter = 1;   
    }

    if (dm_bargraph5.newY >= dm_bargraph5.sizeY) {
      // Increase the bargraph size
      dm_bargraph5.sizeY = dm_bargraph5.sizeY + dm_bargraph5.bargraphSpeed;
      
      // Calculate the new position of the bar
      dm_bargraph5.currentY = dm_bargraph5.bargraphBottom - dm_bargraph5.sizeY;

      // Draw the new bargraph
      dm_spr_barGraph.createSprite(dm_bargraph5.sizeX, dm_bargraph5.sizeY);
      dm_spr_barGraph.fillSprite(TFT_RED);
      dm_spr_barGraph.pushSprite(dm_bargraph5.currentX, dm_bargraph5.currentY);
      dm_spr_barGraph.deleteSprite();

      if (dm_bargraph5.sizeY >= dm_bargraph5.newY){
      // Once the bargraph meets the new value, reset the sequence counter so a new value can be generated
      dm_bargraph5.sCounter = 0;
      }       
    }
    
    if (dm_bargraph5.newY < dm_bargraph5.sizeY){      
      // Decrease the bargraph size
      dm_bargraph5.sizeY = dm_bargraph5.sizeY - dm_bargraph5.bargraphSpeed;

      // To shrink the bar, we'll need to draw a black sprite over the top part of the bar.
            
      // Draw the black sprite
      dm_bg_barGraph.createSprite(dm_bargraph5.maxX, dm_bargraph5.maxY - dm_bargraph5.sizeY);
      dm_bg_barGraph.fillSprite(TFT_BLACK);
      dm_bg_barGraph.pushSprite(dm_bargraph5.currentX, dm_bargraph5.maxY - 2);
      dm_bg_barGraph.deleteSprite();
     
      
      if (dm_bargraph5.sizeY <= dm_bargraph5.newY){
      // Once the bargraph meets the new value, reset the sequence counter so a new value can be generated
      dm_bargraph5.sCounter = 0;
        }
    }    

    dm_bargraph5.previousMillis = currentMillis;    
  }
  
}
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

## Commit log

2022-01-16 Replaced animations for old screen. Added Top/Bottom frame animation
    [Main.ino]
2022-01-17 Added button animation to bottom-right corner
2022-02-28 Added gerber files for PCB manufacture
2022-04-17 Added Fusion 360 and STL exports
    [Back Panel.f3d, Back Panel.stl, Door.f3z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]
2022-04-17 Added parts list
    [PARTS_LIST.xlsx]
2022-04-17 Moved arduino files to their own folder
2022-04-17 Added hinge info to parts list
    [PARTS_LIST.xlsx]
2022-04-17 Updated parts list
    [PARTS_LIST.xlsx]
2022-06-23 added optional door w/ ID cutout
    [Door 5.1 (ID Cutout).f3z, Door 5.1 (ID Cutout).stl]
2022-08-18 Added Mr. Engineer's Top Panel mod to PCB Files/Mr.Engineer's Mods
    [Arky TR595 Top Panel Eagle.brd, Arky TR595 Top Panel Eagle.sch]
